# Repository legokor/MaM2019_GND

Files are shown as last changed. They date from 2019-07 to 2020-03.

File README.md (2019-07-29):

# MaM2019-GND

Lábkiosztás:

| ESP32 | LoRa  | Panel |
|---|---|---|
| 5 | NSS | |
| 12 | | Pin8  |
| 14 | | Pin6  |
| 17 | RESET | |
| 18 | SCK | |
| 19 | MISO  | |
| 23 | MOSI  | |
| 25 | | Pin1  |
| 26 | | Pin2  |
| 27 | | Pin4  |
| 32 | | Pin5  |
| 33 | | Pin3  |
| 34 | DIO0  | |
| 35 | | Pin7  |

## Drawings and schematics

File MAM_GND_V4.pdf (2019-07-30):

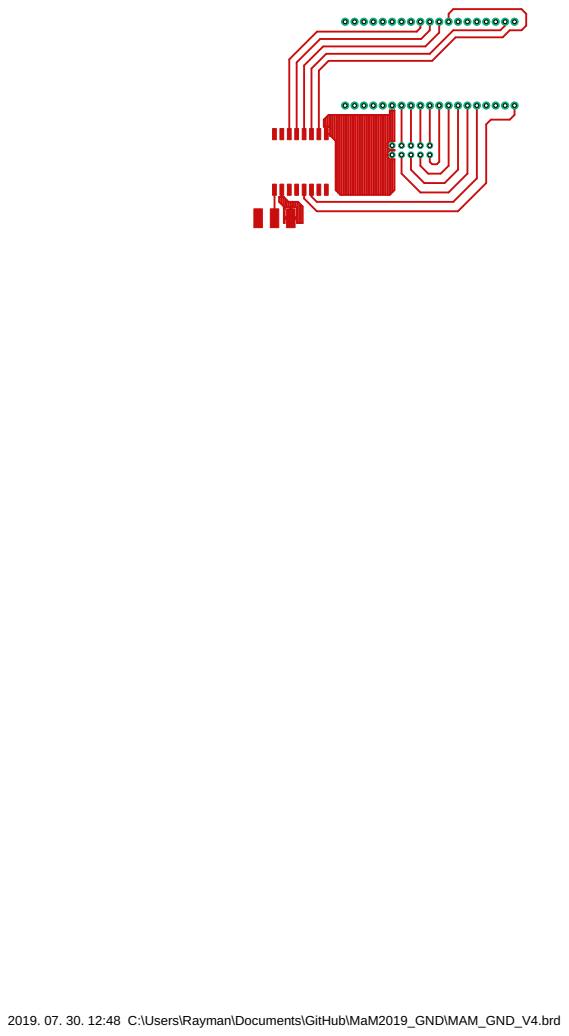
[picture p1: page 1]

2019. 07. 30. 12:48 C:\Users\Rayman\Documents\GitHub\MaM2019_GND\MAM_GND_V4.brd

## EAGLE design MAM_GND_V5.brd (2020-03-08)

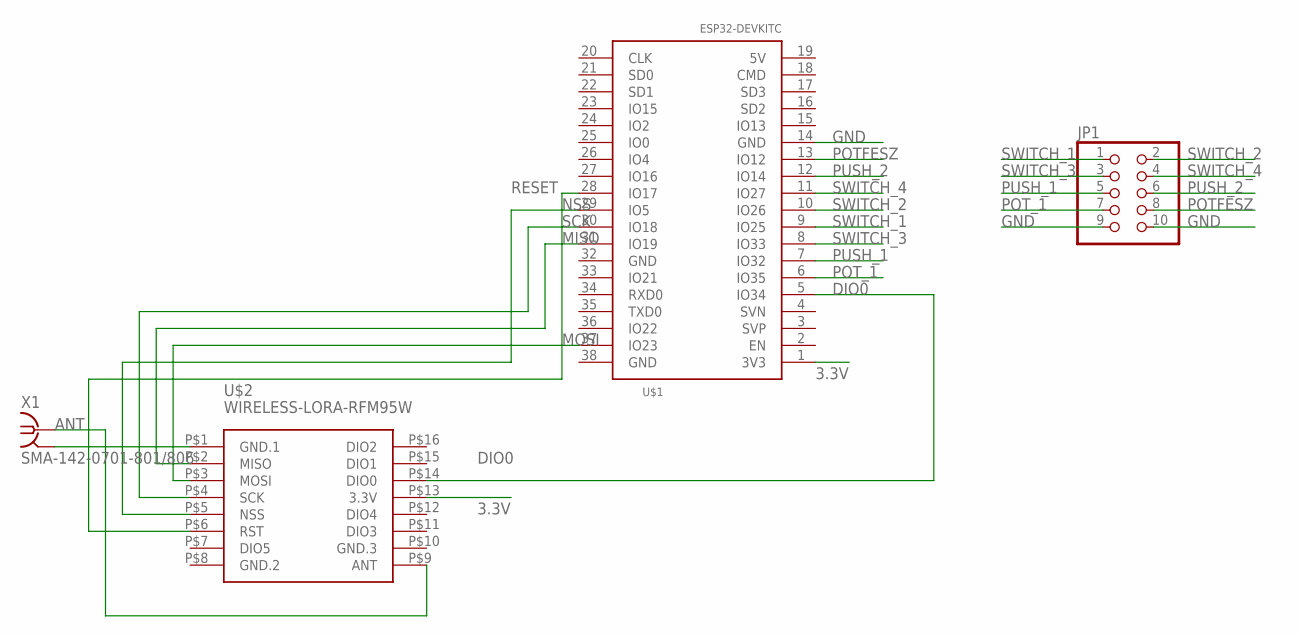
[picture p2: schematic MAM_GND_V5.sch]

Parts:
JP1: PINHD-2X5; 2X05
U$1: ESP32DEVKITC; ESP32-DEVKITC
U$2: WIRELESS-LORA-RFM95W; LORA-BREAKOUT
X1: SMA-142-0701-801/806; J502-ND-142-0701-801/806

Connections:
3.3V: U$1.1 (3V3), U$2.P$13 (3.3V)
ANT: U$2.P$9 (ANT), X1.1
DIO0: U$1.5 (IO34), U$2.P$14 (DIO0)
GND: JP1.9, JP1.10, U$1.14 (GND), U$2.P$1 (GND.1), X1.G@1 (2), X1.G@2 (2), X1.G@3 (2), X1.G@4 (2)
GND.2: U$2.P$8 (GND.2)
GND.3: U$2.P$10 (GND.3)
MISO: U$1.31 (IO19), U$2.P$2 (MISO)
MOSI: U$1.37 (IO23), U$2.P$3 (MOSI)
NSS: U$1.29 (IO5), U$2.P$5 (NSS)
POTFESZ: JP1.8, U$1.13 (IO12)
POT_1: JP1.7, U$1.6 (IO35)
PUSH_1: JP1.5, U$1.7 (IO32)
PUSH_2: JP1.6, U$1.12 (IO14)
RESET: U$1.28 (IO17), U$2.P$6 (RST)
SCK: U$1.30 (IO18), U$2.P$4 (SCK)
SWITCH_1: JP1.1, U$1.9 (IO25)
SWITCH_2: JP1.2, U$1.10 (IO26)
SWITCH_3: JP1.3, U$1.8 (IO33)
SWITCH_4: JP1.4, U$1.11 (IO27)

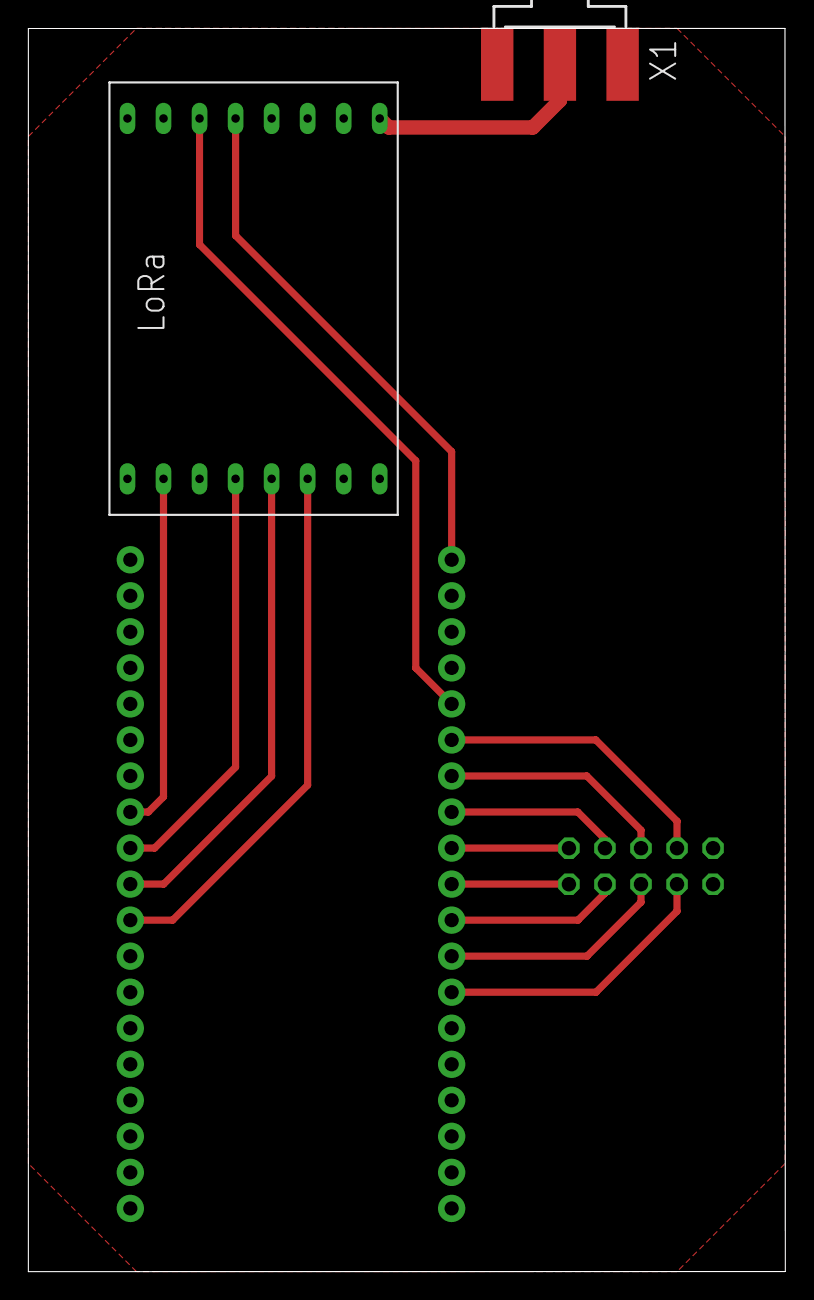
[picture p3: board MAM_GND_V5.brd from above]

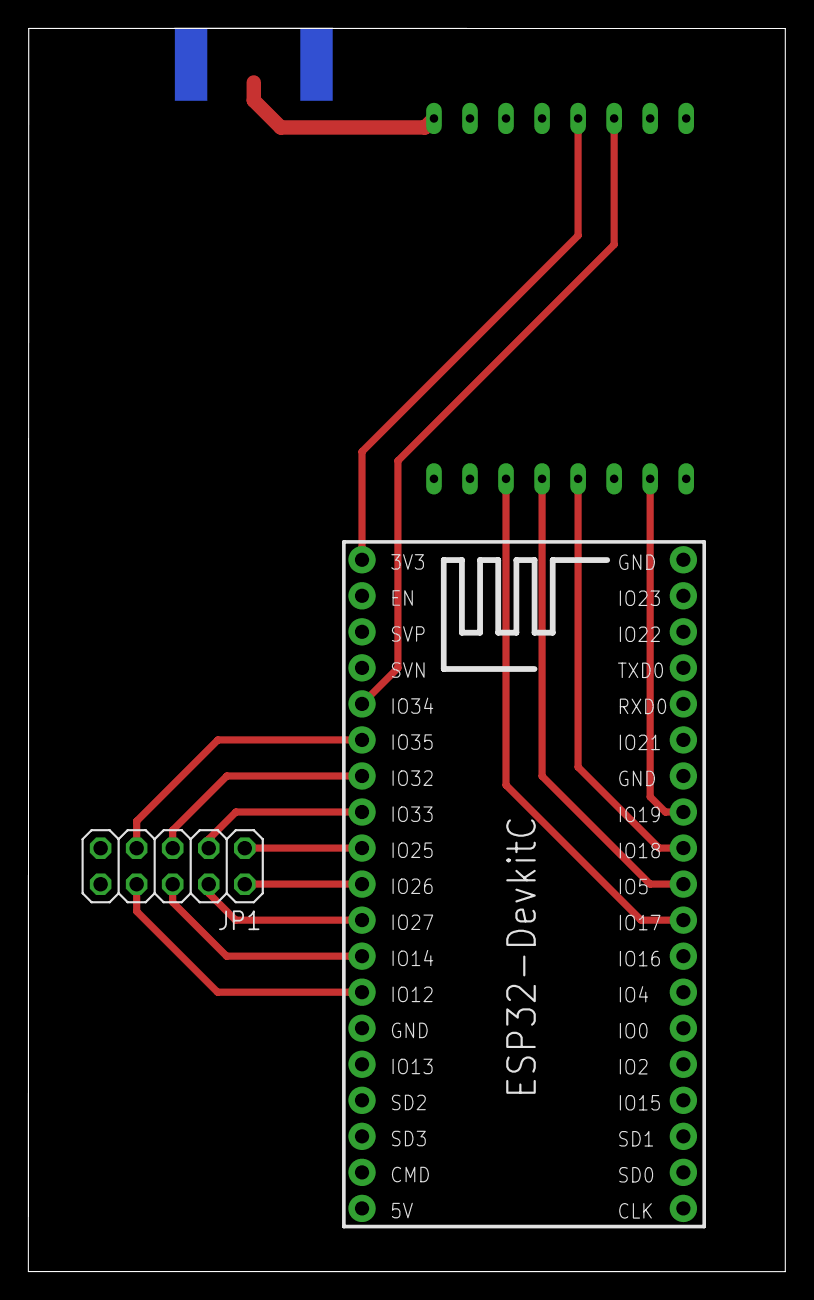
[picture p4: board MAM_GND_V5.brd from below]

Board: 2 copper layers, 53.4 x 87.6 mm, 4 parts (2 on the bottom side), 17 nets.

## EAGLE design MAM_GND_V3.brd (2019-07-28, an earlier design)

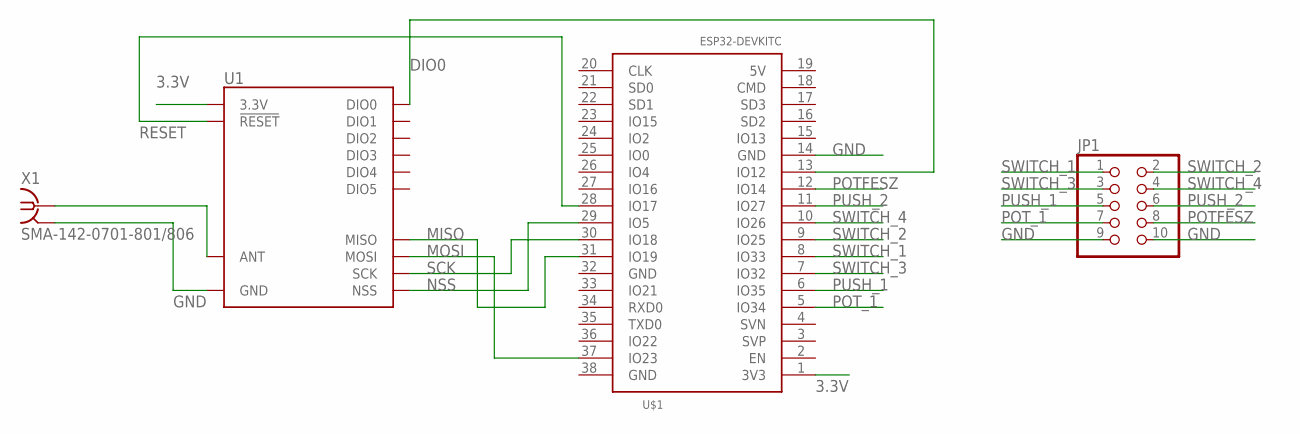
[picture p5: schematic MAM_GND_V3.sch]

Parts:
JP1: PINHD-2X5; 2X05
U1: RFM95W; RFM95/96/97/98W
U$1: ESP32DEVKITC; ESP32-DEVKITC
X1: SMA-142-0701-801/806; J502-ND-142-0701-801/806

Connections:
3.3V: U1.3.3V, U$1.1 (3V3)
DIO0: U1.DIO0, U$1.13 (IO12)
GND: JP1.9, JP1.10, U1.GND@1 (GND), U1.GND@2 (GND), U1.GND@3 (GND), U$1.14 (GND), X1.G@1 (2), X1.G@2 (2), X1.G@3 (2), X1.G@4 (2)
MISO: U1.MISO, U$1.31 (IO19)
MOSI: U1.MOSI, U$1.37 (IO23)
unnamed: U1.ANT, X1.1
NSS: U1.NSS, U$1.29 (IO5)
POTFESZ: JP1.8, U$1.12 (IO14)
POT_1: JP1.7, U$1.5 (IO34)
PUSH_1: JP1.5, U$1.6 (IO35)
PUSH_2: JP1.6, U$1.11 (IO27)
RESET: U1.!RESET, U$1.28 (IO17)
SCK: U1.SCK, U$1.30 (IO18)
SWITCH_1: JP1.1, U$1.8 (IO33)
SWITCH_2: JP1.2, U$1.9 (IO25)
SWITCH_3: JP1.3, U$1.7 (IO32)
SWITCH_4: JP1.4, U$1.10 (IO26)

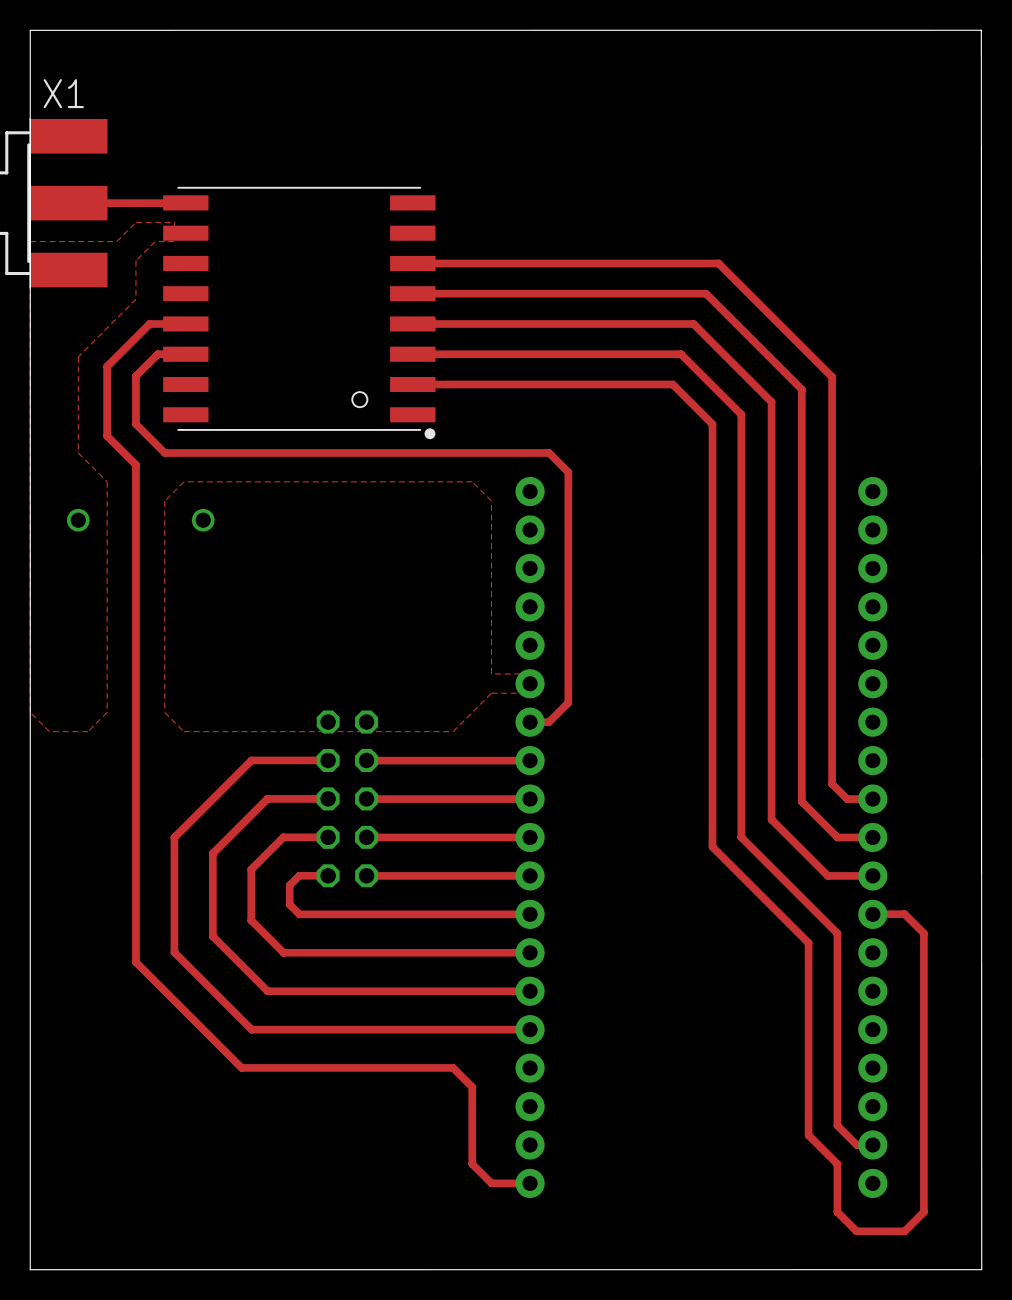
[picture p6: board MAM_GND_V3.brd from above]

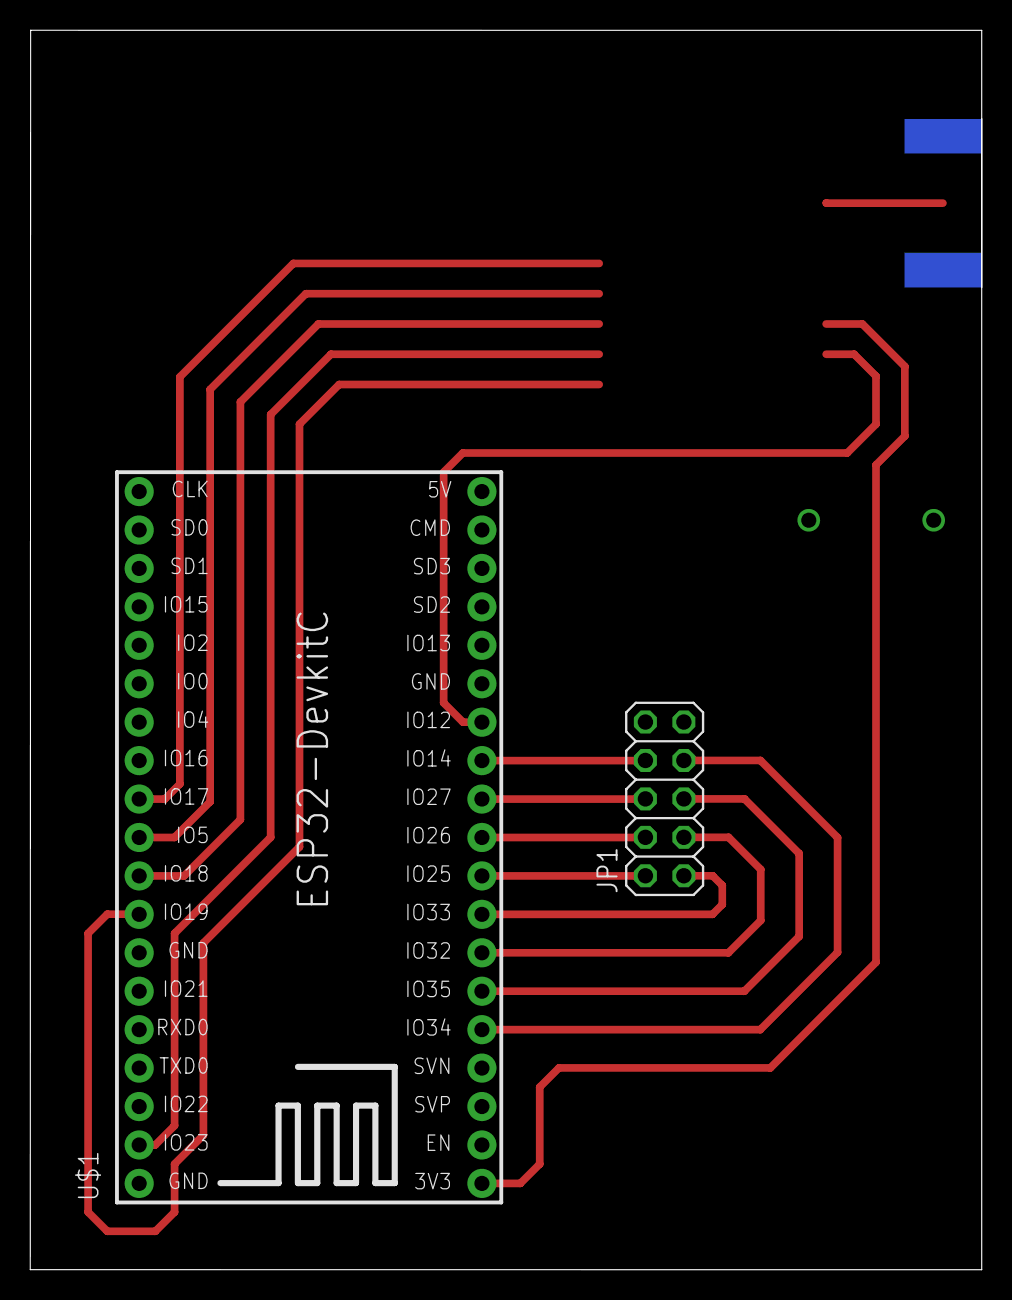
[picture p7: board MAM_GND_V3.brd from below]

Board: 2 copper layers, 62.9 x 81.9 mm, 4 parts (2 on the bottom side), 17 nets.

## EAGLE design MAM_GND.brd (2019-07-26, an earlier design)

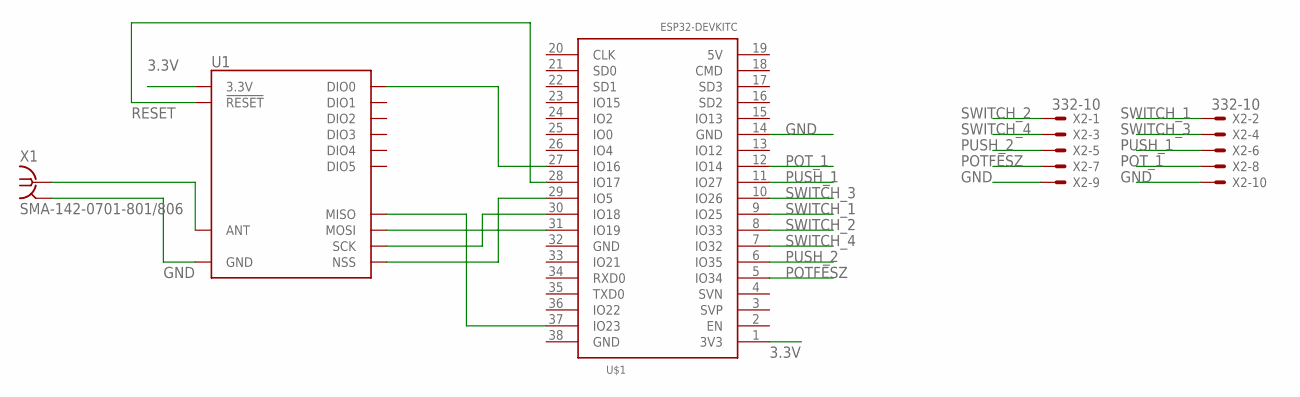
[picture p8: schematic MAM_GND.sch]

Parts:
U1: RFM95W; RFM95/96/97/98W
U$1: ESP32DEVKITC; ESP32-DEVKITC
X1: SMA-142-0701-801/806; J502-ND-142-0701-801/806
X2: 332-10

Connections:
3.3V: U1.3.3V, U$1.1 (3V3)
GND: U1.GND@1 (GND), U1.GND@2 (GND), U1.GND@3 (GND), U$1.14 (GND), X1.G@1 (2), X1.G@2 (2), X1.G@3 (2), X1.G@4 (2), X2.9, X2.10
unnamed: U1.MISO, U$1.37 (IO23)
unnamed: U1.MOSI, U$1.31 (IO19)
unnamed: U1.SCK, U$1.30 (IO18)
unnamed: U1.NSS, U$1.29 (IO5)
unnamed: U1.DIO0, U$1.27 (IO16)
unnamed: U1.ANT, X1.1
POTFESZ: U$1.5 (IO34), X2.7
POT_1: U$1.12 (IO14), X2.8
PUSH_1: U$1.11 (IO27), X2.6
PUSH_2: U$1.6 (IO35), X2.5
RESET: U1.!RESET, U$1.28 (IO17)
SWITCH_1: U$1.9 (IO25), X2.2
SWITCH_2: U$1.8 (IO33), X2.1
SWITCH_3: U$1.10 (IO26), X2.4
SWITCH_4: U$1.7 (IO32), X2.3

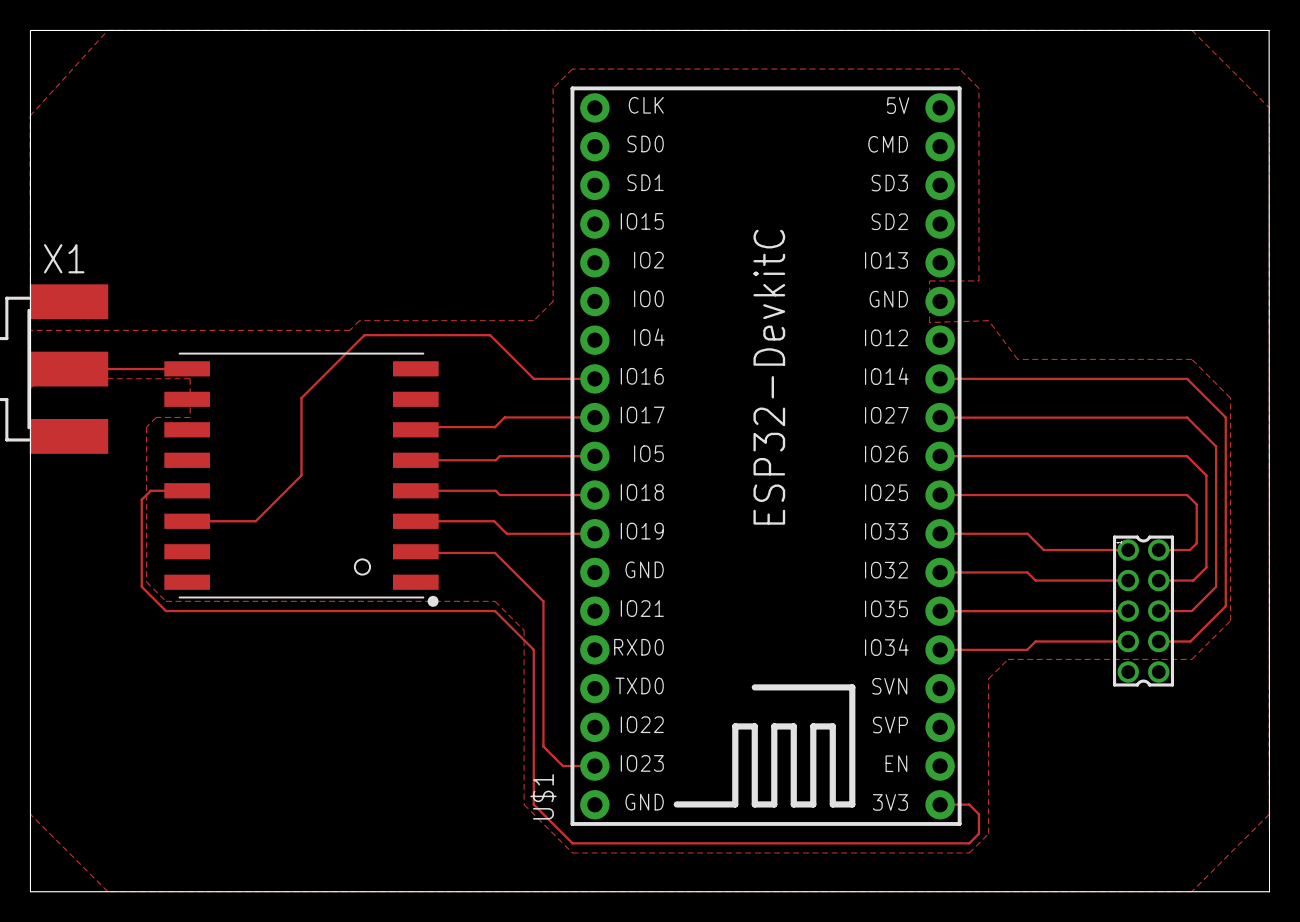
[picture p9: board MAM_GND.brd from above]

Board: 2 copper layers, 81.3 x 56.5 mm, 4 parts (0 on the bottom side), 17 nets.

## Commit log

2019-07-28 GND nyákterv
    Sajnos, a két földet össze kell kötni egy dróttal, de ezen kívül remélem ez a végleges változat.
    [MAM_GND_V3.brd, MAM_GND_V3.sch]
2019-07-29 GND nyák
    Sikerült megoldani a föld külön összekötése nélkül :)
    [MAM_GND_V4.brd, MAM_GND_V4.sch]
2019-07-30 added pdf to print
2019-09-13 Lora modul kapcsolási rajza
    Ezen a könyvtáron belül az RFM95W-t használtam a GND tervezésénél.
2020-03-08 Legújabb GND panel terv
    [MAM_GND_V5.brd, MAM_GND_V5.sch]

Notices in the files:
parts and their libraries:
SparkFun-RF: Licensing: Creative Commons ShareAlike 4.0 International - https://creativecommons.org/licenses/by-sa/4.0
